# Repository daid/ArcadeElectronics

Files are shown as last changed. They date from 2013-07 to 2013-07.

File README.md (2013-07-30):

ArcadeElectronics
=================

V-USB based Electronics board for Arcade controls

Features
========
* V-USB based USB Interface emulating a mouse, keyboard and gamepad with full configuration of button mapping (no drivers required)
* 4 way digital joystick + 7 button connections. 4 way joystick inputs can also be used for analogue joystick.
* 16 LED output pins (max current total 200mA) which can also be used as inputs. And 8 are also mapped wired to 1A higher power outputs with external power supply (optional hardware)
* RFM12 wireless transiever (optional hardware) allows communication with other controllers and building of wireless controllers with 2 boards.
* Full open-source hardware & open-source software - Build with Free-Open-Source tools (KiCAD & AVR-GCC)
* ISP header to program the AVR (reset line can be cut and re-wired to have the board function as an programmer on the same header)
* USB-micro or USB-B connector depending on your taste
* Different small board designs, depending on your requirements:
	* 100x50mm: Fully featured, has option for 16 LED outputs, of which 8 can be configured for high power. Has wireless RFM12 option. 4 direction inputs, 7 button inputs
	* 50x50mm: Only base features with screw connectors. 4 direction inputs, 7 button inputs.
	* 50x25mm: Only base features with pin connectors. 4 direction inputs, 7 button inputs 
	* 25x25mm: Only base features with pin connectors, components on both sides. 4 direction inputs, 7 button inputs 

Organization
============
The following directories are in this project:
* Electronics - Contain the KiCAD design files
* Software/firmware/bootloader - Modified HIDBoot
* Software/firmware/arcade - Main firmware for the Arcade controller
* Software/computer/commandline - Commandline application to change the controller configuration, and control the LEDs
* Software/computer/lib - Library shared between different applications for custom commands to the ArcadeController
* Software/computer/gui_test - SDL based application to verify the Keyboard/Joystick/Mouse inputs

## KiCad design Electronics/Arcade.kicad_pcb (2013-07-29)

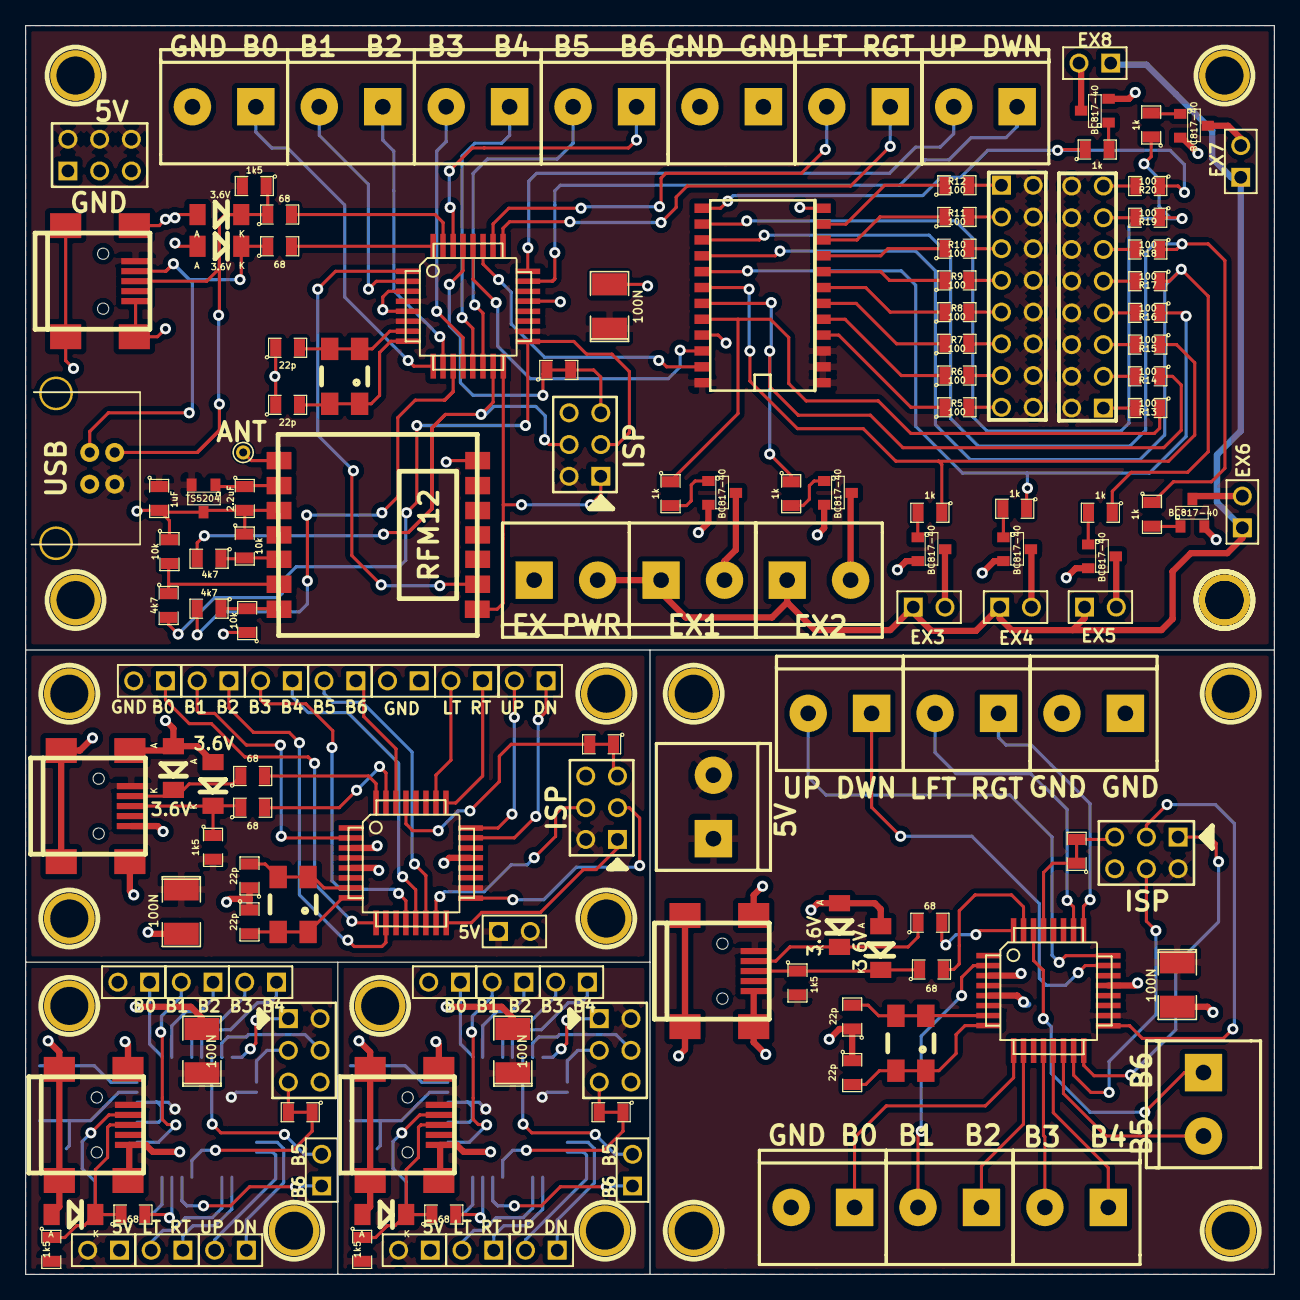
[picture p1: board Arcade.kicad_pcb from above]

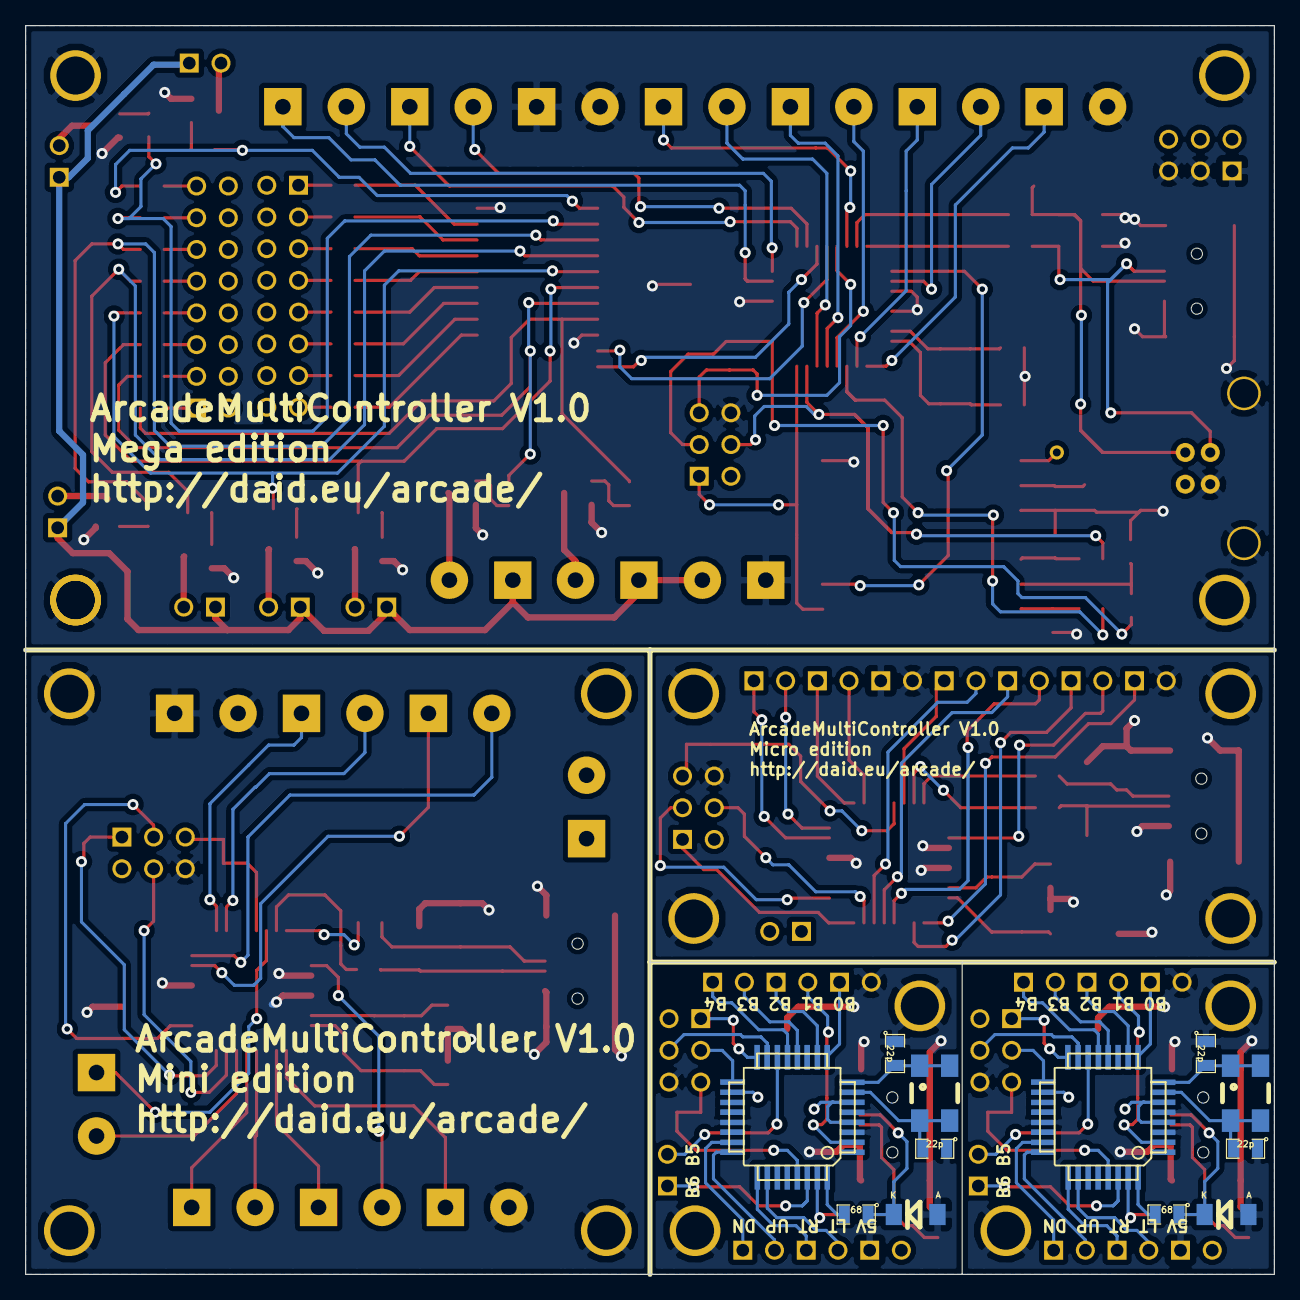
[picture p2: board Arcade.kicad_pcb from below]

Board: 2 copper layers, 100.0 x 100.0 mm, 176 parts (12 on the bottom side), 144 nets.

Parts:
1PIN, 1PIN#2, 1PIN#3, 1PIN#4, 1PIN#5, 1PIN#6, 1PIN#7, 1PIN#8, 1PIN#9, 1PIN#10, 1PIN#11, 1PIN#12, 1PIN#13, 1PIN#14, 1PIN#15, 1PIN#16, 1PIN#17: P***; 1pin
C1, C2, C6, C7, C9, C10, C12, C12#2, C13, C13#2: 22p; SM0805
C3, C8, C11, C14, C14#2: 100N; SM1210L
C4: 1uF; SM0805
C5: 2.2uF; SM0805
CON1, CON2, CON3, CON4, CON4#2: USB-MINI-B; USB_MINI_B
D1, D2, D3, D4, D5, D6, D7, D7#2, D8, D8#2: 3.6V; Diode-MiniMELF_Standard_RevA_27July2010
IC1, IC2, IC3, IC4, IC4#2: ATMEGA8A-A; TQFP32
J1: USB; USB_B_SHORT
P1, P22, P30, P40, P40#2: ISP; pin_array_3x2
P2, P23: UP DWN; mors_2p
P3, P24: LFT RGT; mors_2p
P4, P25: GND GND; mors_2p
P5, P26: B5 B6; mors_2p
P6, P27: B3 B4; mors_2p
P7, P28: B1 B2; mors_2p
P8, P29: GND B0; mors_2p
P9: ANT; PINTST
P10, P11: CONN_8X2; pin_array_8x2
P12: EX1; mors_2p
P13: EX_PWR; mors_2p
P14: CONN_3X2; pin_array_3x2
P15: EX2; mors_2p
P16: EX3; PIN_ARRAY_2X1
P17: EX4; PIN_ARRAY_2X1
P18: EX5; PIN_ARRAY_2X1
P19: EX6; PIN_ARRAY_2X1
P20: EX7; PIN_ARRAY_2X1
P21: EX8; PIN_ARRAY_2X1
P31, P41, P41#2: UP DWN; PIN_ARRAY_2X1
P32, P42, P42#2: LFT RGT; PIN_ARRAY_2X1
P33: GND GND; PIN_ARRAY_2X1
P34, P44, P44#2: B5 B6; PIN_ARRAY_2X1
P35, P45, P45#2: B3 B4; PIN_ARRAY_2X1
P36, P46, P46#2: B1 B2; PIN_ARRAY_2X1
P37, P47, P47#2: GND B0; PIN_ARRAY_2X1
P38, P48, P48#2: 5V; PIN_ARRAY_2X1
P39: 5V; mors_2p
Q1, Q2, Q3, Q4, Q5, Q6, Q7, Q8: BC817-40; SOT23
R1, R35, R39, R43, R43#2: 1k5; SM0805
R2, R3, R36, R37, R40, R41, R44, R44#2, R45, R45#2: 68; SM0805
R4, R38, R42, R46, R46#2: 0; SM0805
R5, R6, R7, R8, R9, R10, R11, R12, R13, R14, R15, R16, R17, R18, R19, R20: 100; SM0805
R21, R22, R23: 4k7; SM0805
R24, R25, R26: 10k; SM0805
R27, R28, R29, R30, R31, R32, R33, R34: 1k; SM0805
U1: PCA9532; SO24E
U2: RFM12
U3: TS5204; SOT23
X1, X2, X3, X4, X4#2: 16Mhz; Crystal_SMD_0603_4Pads_RevA_09Aug2010

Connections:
/B0: IC1.9, P8.1
/B0_2: IC2.9, P29.1
/B0_3: IC3.9, P37.1
/B0_4: IC4.9, IC4#2.9, P47.1, P47#2.1
/B1: IC1.2, P7.2
/B1_2: IC2.2, P28.2
/B1_3: IC3.2, P36.2
/B1_4: IC4.2, IC4#2.2, P46.2, P46#2.2
/B2: IC1.10, P7.1
/B2_2: IC2.10, P28.1
/B2_3: IC3.10, P36.1
/B2_4: IC4.10, IC4#2.10, P46.1, P46#2.1
/B3: IC1.12, P6.2
/B3_2: IC2.12, P27.2
/B3_3: IC3.12, P35.2
/B3_4: IC4.12, IC4#2.12, P45.2, P45#2.2
/B4: IC1.13, P6.1
/B4_2: IC2.13, P27.1
/B4_3: IC3.13, P35.1
/B4_4: IC4.13, IC4#2.13, P45.1, P45#2.1
/B5: IC1.14, P5.2
/B5_2: IC2.14, P26.2
/B5_3: IC3.14, P34.2
/B5_4: IC4.14, IC4#2.14, P44.2, P44#2.2
/B6: IC1.30, P5.1
/B6_2: IC2.30, P26.1
/B6_3: IC3.30, P34.1
/B6_4: IC4.30, IC4#2.30, P44.1, P44#2.1
/BTN_DOWN: IC1.23, P2.1
/BTN_DOWN_2: IC2.23, P23.1
/BTN_DOWN_3: IC3.23, P31.1
/BTN_DOWN_4: IC4.23, IC4#2.23, P41.1, P41#2.1
/BTN_LEFT: IC1.26, P3.2
/BTN_LEFT_2: IC2.26, P24.2
/BTN_LEFT_3: IC3.26, P32.2
/BTN_LEFT_4: IC4.26, IC4#2.26, P42.2, P42#2.2
/BTN_RIGHT: IC1.25, P3.1
/BTN_RIGHT_2: IC2.25, P24.1
/BTN_RIGHT_3: IC3.25, P32.1
/BTN_RIGHT_4: IC4.25, IC4#2.25, P42.1, P42#2.1
/BTN_UP: IC1.24, P2.2
/BTN_UP_2: IC2.24, P23.2
/BTN_UP_3: IC3.24, P31.2
/BTN_UP_4: IC4.24, IC4#2.24, P41.2, P41#2.2
/EX1: P12.2, Q2.3
/EX1_OUT: R13.1, R30.1, U1.20
/EX2: P15.2, Q3.3
/EX2_OUT: R14.1, R29.1, U1.19
/EX3: P16.2, Q4.3
/EX3_OUT: R15.1, R28.1, U1.18
/EX4: P17.2, Q5.3
/EX4_OUT: R16.1, R27.1, U1.17
/EX5: P18.2, Q1.3
/EX5_OUT: R17.1, R31.1, U1.16
/EX6: P19.2, Q6.3
/EX6_OUT: R18.1, R32.1, U1.15
/EX7: P20.2, Q7.3
/EX7_OUT: R19.1, R33.1, U1.14
/EX8: P21.2, Q8.3
/EX8_OUT: R20.1, R34.1, U1.13
/EX_PWR: P12.1, P13.2, P15.1, P16.1, P17.1, P18.1, P19.1, P20.1, P21.1
/MISO: IC1.16, P1.1, U2.1
/MISO_2: IC2.16, P22.1
/MISO_3: IC3.16, P30.1
/MISO_4: IC4.16, IC4#2.16, P40.1, P40#2.1
/MOSI: IC1.15, P1.4, R23.2
/MOSI_2: IC2.15, P22.4
/MOSI_3: IC3.15, P30.4
/MOSI_4: IC4.15, IC4#2.15, P40.4, P40#2.4
/RESET: IC1.29, P1.5, R4.1, R4.2
/RESET_2: IC2.29, P22.5, R38.1, R38.2
/RESET_3: IC3.29, P30.5, R42.1, R42.2
/RESET_4: IC4.29, IC4#2.29, P40.5, P40#2.5, R46.1, R46.2, R46#2.1, R46#2.2
/RF_IRQ: IC1.1, U2.2
/RF_SEL: IC1.11, R21.2
/SCK: IC1.17, P1.3, R22.2
/SCK_2: IC2.17, P22.3
/SCK_3: IC3.17, P30.3
/SCK_4: IC4.17, IC4#2.17, P40.3, P40#2.3
/SCL: IC1.28, U1.22
/SDA: IC1.27, U1.23
/USB_D+: IC1.32, R2.2
/USB_D+_2: IC2.32, R36.2
/USB_D+_3: IC3.32, R40.2
/USB_D+_4: IC4.32, IC4#2.32, R44.2, R44#2.2
/USB_D-: IC1.31, R3.2
/USB_D-_2: IC2.31, R37.2
/USB_D-_3: IC3.31, R41.2
/USB_D-_4: IC4.31, IC4#2.31, R45.2, R45#2.2
/V3.3: C5.1, U2.9, U3.1
GND: 1PIN.1, 1PIN#2.1, 1PIN#3.1, 1PIN#4.1, 1PIN#5.1, 1PIN#6.1, 1PIN#7.1, 1PIN#8.1, 1PIN#9.1, 1PIN#10.1, 1PIN#11.1, 1PIN#12.1, 1PIN#13.1, 1PIN#14.1, 1PIN#15.1, 1PIN#16.1, 1PIN#17.1, C1.1, C2.1, C3.2, C4.2, C5.2, C6.1, C7.1, C8.2, C9.1, C10.1, C11.2, C12.1, C12#2.1, C13.1, C13#2.1, C14.2, C14#2.2, CON1.5, CON1.6, CON1.7, CON1.8, CON1.9, CON2.5, CON2.6, CON2.7, CON2.8, CON2.9, CON3.5, CON3.6, CON3.7, CON3.8, CON3.9, CON4.5, CON4.6, CON4.7, CON4.8, CON4.9, CON4#2.5, CON4#2.6, CON4#2.7, CON4#2.8, CON4#2.9, D1.1, D2.1, D3.1, D4.1, D5.1, D6.1, D7.1, D7#2.1, D8.1, D8#2.1, IC1.3, IC1.5, IC1.21, IC2.3, IC2.5, IC2.21, IC3.3, IC3.5, IC3.21, IC4.3, IC4.5, IC4.21, IC4#2.3, IC4#2.5, IC4#2.21, J1.4, J1.5, J1.6, P1.6, P4.1, P4.2, P8.2, P13.1, P14.1, P14.3, P14.5, P22.6, P25.1, P25.2, P29.2, P30.6, P33.1, P33.2, P37.2, P40.6, P40#2.6, P47.2, P47#2.2, P48.1, P48#2.1, Q1.2, Q2.2, Q3.2, Q4.2, Q5.2, Q6.2, Q7.2, Q8.2, R24.1, R25.1, R26.1, U1.12, U1.21, U2.7, U2.10, U3.3
unnamed: C9.2, IC3.7, X3.2
unnamed: CON2.2, D3.2, R36.1
unnamed: C10.2, IC3.8, X3.1
unnamed: CON2.3, D4.2, R35.1, R37.1
unnamed: C6.2, IC2.7, X2.2
unnamed: C7.2, IC2.8, X2.1
unnamed: CON4.3, CON4#2.3, D8.2, D8#2.2, R43.1, R43#2.1, R45.1, R45#2.1
unnamed: CON4.2, CON4#2.2, D7.2, D7#2.2, R44.1, R44#2.1
unnamed: CON3.3, D6.2, R39.1, R41.1
unnamed: C12.2, C12#2.2, IC4.7, IC4#2.7, X4.2, X4#2.2
unnamed: C13.2, C13#2.2, IC4.8, IC4#2.8, X4.1, X4#2.1
unnamed: CON3.2, D5.2, R40.1
unnamed: R8.1, U1.7
unnamed: P10.1, R12.2
unnamed: R12.1, U1.11
unnamed: P10.3, R11.2
unnamed: R11.1, U1.10
unnamed: R10.1, U1.9
unnamed: R9.1, U1.8
unnamed: R7.1, U1.6
unnamed: R6.1, U1.5
unnamed: R5.1, U1.4
unnamed: P10.15, R5.2
unnamed: P10.13, R6.2
unnamed: P10.11, R7.2
unnamed: P10.9, R8.2
unnamed: P10.7, R9.2
unnamed: P10.5, R10.2
unnamed: C1.2, IC1.7, X1.2
unnamed: C2.2, IC1.8, X1.1
unnamed: P9.1, U2.8
unnamed: P11.15, R20.2
unnamed: Q4.1, R28.2
unnamed: P11.13, R19.2
unnamed: Q3.1, R29.2
unnamed: Q5.1, R27.2
unnamed: Q2.1, R30.2
unnamed: P11.9, R17.2
unnamed: P11.11, R18.2
unnamed: P11.5, R15.2
unnamed: P11.1, R13.2
unnamed: P11.3, R14.2
unnamed: P11.7, R16.2
unnamed: Q7.1, R33.2
unnamed: Q6.1, R32.2
unnamed: Q8.1, R34.2
unnamed: Q1.1, R31.2
unnamed: CON1.3, D2.2, J1.2, R1.1, R3.1
unnamed: CON1.2, D1.2, J1.3, R2.1
unnamed: R21.1, R26.2, U2.14
unnamed: R22.1, R25.2, U2.13
unnamed: R23.1, R24.2, U2.12
VCC: C3.1, C4.1, C8.1, C11.1, C14.1, C14#2.1, CON1.1, CON2.1, CON3.1, CON4.1, CON4#2.1, IC1.4, IC1.6, IC1.18, IC2.4, IC2.6, IC2.18, IC3.4, IC3.6, IC3.18, IC4.4, IC4.6, IC4.18, IC4#2.4, IC4#2.6, IC4#2.18, J1.1, P1.2, P10.2, P10.4, P10.6, P10.8, P10.10, P10.12, P10.14, P10.16, P11.2, P11.4, P11.6, P11.8, P11.10, P11.12, P11.14, P11.16, P14.2, P14.4, P14.6, P22.2, P30.2, P38.1, P38.2, P39.1, P39.2, P40.2, P40#2.2, P48.2, P48#2.2, R1.2, R35.2, R39.2, R43.2, R43#2.2, U1.1, U1.2, U1.3, U1.24, U3.2

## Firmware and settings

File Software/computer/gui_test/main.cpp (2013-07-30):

#include <SDL/SDL.h>
#include "gui.h"

typedef struct
{
    int x, y, w, h;
} keyPos_t;

keyPos_t keyPos[SDLK_LAST];

void init_keyPos();

void draw_button(int active, const char* name, int x, int y, int w, int h)
{
    char buffer[32];
    strcpy(buffer, name);
    buffer[2*w] = '\0';
    buffer[0] = toupper(buffer[0]);
    if (active)
    {
        draw_fill(x * 12, y * 12, w * 12, h * 12);
        draw_text(x * 12 + w * 12 / 2 - strlen(buffer) * 6 / 2, y * 12 + h * 6 - 3, buffer, 0);
    }else{
        draw_rect(x * 12, y * 12, w * 12, h * 12);
        draw_text(x * 12 + w * 12 / 2 - strlen(buffer) * 6 / 2, y * 12 + h * 6 - 3, buffer);
    }
}

int main(int argc, char** argv)
{
    init_gui();
    init_keyPos();
    
    while(true)
    {
        SDL_Event event;
        while (SDL_PollEvent(&event)) 
        {
            switch (event.type) 
            {
            case SDL_QUIT:
                return 0;
            }
        }
        SDL_JoystickUpdate();
        
        int keyCount;
        Uint8* keys = SDL_GetKeyState(&keyCount);
        for(int n=0; n<keyCount; n++)
        {
            if (keyPos[n].x != 0)
            {
                char buffer[64];
                strcpy(buffer, SDL_GetKeyName(SDLKey(n)));
                if (strncmp(buffer, "left ", 5) == 0)
                    strcpy(buffer, buffer + 5);
                if (strncmp(buffer, "right ", 6) == 0)
                    strcpy(buffer, buffer + 6);
                draw_button(keys[n], buffer, keyPos[n].x, keyPos[n].y, keyPos[n].w, keyPos[n].h);
            }else{
                if (keys[n])
                    draw_text(0, 0, SDL_GetKeyName(SDLKey(n)));
            }
        }
        int x, y;
        int button = SDL_GetMouseState(&x, &y);
        draw_button(button & SDL_BUTTON(1), "Left", 1, 18, 2, 2);
        draw_button(button & SDL_BUTTON(2), "Mid", 3, 18, 2, 2);
        draw_button(button & SDL_BUTTON(3), "Right", 5, 18, 2, 2);
        draw_rect(12, 20*12, 6*12, 6*12);
        draw_rect(12 + x * 6*12 / 640, 20*12 + y * 6*12 / 480, 2, 2);
        SDL_GetRelativeMouseState(&x, &y);
        draw_rect(12 + 6*12/2 + x/2, 20*12 + 6*12 / 2 + y/2, 2, 2);
        
        for(int n=0; n<SDL_NumJoysticks(); n++)
        {
            
        }
        
        gui_update();
    }
}


void init_keyPos()
{
    keyPos[SDLK_ESCAPE] = {1, 1, 3, 2};
    
    keyPos[SDLK_F1] = {5, 1, 2, 2};
    keyPos[SDLK_F2] = {7, 1, 2, 2};
    keyPos[SDLK_F3] = {9, 1, 2, 2};
    keyPos[SDLK_F4] = {11, 1, 2, 2};
    keyPos[SDLK_F5] = {14, 1, 2, 2};
    keyPos[SDLK_F6] = {16, 1, 2, 2};
    keyPos[SDLK_F7] = {18, 1, 2, 2};
    keyPos[SDLK_F8] = {20, 1, 2, 2};
    keyPos[SDLK_F9] = {23, 1, 2, 2};
    keyPos[SDLK_F10] = {25, 1, 2, 2};
    keyPos[SDLK_F11] = {27, 1, 2, 2};
    keyPos[SDLK_F12] = {29, 1, 2, 2};

    keyPos[SDLK_BACKQUOTE] = {1, 4, 2, 2};
    keyPos[SDLK_1] = {3, 4, 2, 2};
    keyPos[SDLK_2] = {5, 4, 2, 2};
    keyPos[SDLK_3] = {7, 4, 2, 2};
    keyPos[SDLK_4] = {9, 4, 2, 2};
    keyPos[SDLK_5] = {11, 4, 2, 2};
    keyPos[SDLK_6] = {13, 4, 2, 2};
    keyPos[SDLK_7] = {15, 4, 2, 2};
    keyPos[SDLK_8] = {17, 4, 2, 2};
    keyPos[SDLK_9] = {19, 4, 2, 2};
    keyPos[SDLK_0] = {21, 4, 2, 2};
    keyPos[SDLK_MINUS] = {23, 4, 2, 2};
    keyPos[SDLK_EQUALS] = {25, 4, 2, 2};
    keyPos[SDLK_BACKSPACE] = {27, 4, 4, 2};

    keyPos[SDLK_TAB] = {1, 6, 3, 2};
    keyPos[SDLK_q] = {4, 6, 2, 2};
    keyPos[SDLK_w] = {6, 6, 2, 2};
    keyPos[SDLK_e] = {8, 6, 2, 2};
    keyPos[SDLK_r] = {10, 6, 2, 2};
    keyPos[SDLK_t] = {12, 6, 2, 2};
    keyPos[SDLK_y] = {14, 6, 2, 2};
    keyPos[SDLK_u] = {16, 6, 2, 2};
    keyPos[SDLK_i] = {18, 6, 2, 2};
    keyPos[SDLK_o] = {20, 6, 2, 2};
    keyPos[SDLK_p] = {22, 6, 2, 2};
    keyPos[SDLK_LEFTBRACKET] = {24, 6, 2, 2};
    keyPos[SDLK_RIGHTBRACKET] = {26, 6, 2, 2};
    keyPos[SDLK_BACKSLASH] = {28, 6, 3, 2};

    keyPos[SDLK_CAPSLOCK] = {1, 8, 4, 2};
    keyPos[SDLK_a] = {5, 8, 2, 2};
    keyPos[SDLK_s] = {7, 8, 2, 2};
    keyPos[SDLK_d] = {9, 8, 2, 2};
    keyPos[SDLK_f] = {11, 8, 2, 2};
    keyPos[SDLK_g] = {13, 8, 2, 2};
    keyPos[SDLK_h] = {15, 8, 2, 2};
    keyPos[SDLK_j] = {17, 8, 2, 2};
    keyPos[SDLK_k] = {19, 8, 2, 2};
    keyPos[SDLK_l] = {21, 8, 2, 2};
    keyPos[SDLK_SEMICOLON] = {23, 8, 2, 2};
    keyPos[SDLK_QUOTE] = {25, 8, 2, 2};
    keyPos[SDLK_RETURN] = {27, 8, 4, 2};

    keyPos[SDLK_LSHIFT] = {1, 10, 5, 2};
    keyPos[SDLK_z] = {6, 10, 2, 2};
    keyPos[SDLK_x] = {8, 10, 2, 2};
    keyPos[SDLK_c] = {10, 10, 2, 2};
    keyPos[SDLK_v] = {12, 10, 2, 2};
    keyPos[SDLK_b] = {14, 10, 2, 2};
    keyPos[SDLK_n] = {16, 10, 2, 2};
    keyPos[SDLK_m] = {18, 10, 2, 2};
    keyPos[SDLK_COMMA] = {20, 10, 2, 2};
    keyPos[SDLK_PERIOD] = {22, 10, 2, 2};
    keyPos[SDLK_SLASH] = {24, 10, 2, 2};
    keyPos[SDLK_RSHIFT] = {26, 10, 5, 2};

    keyPos[SDLK_LCTRL] = {1, 12, 3, 2};
    keyPos[SDLK_LSUPER] = {4, 12, 3, 2};
    keyPos[SDLK_LALT] = {7, 12, 3, 2};
    keyPos[SDLK_SPACE] = {10, 12, 9, 2};
    keyPos[SDLK_RALT] = {19, 12, 3, 2};
    keyPos[SDLK_RSUPER] = {22, 12, 3, 2};
    keyPos[SDLK_MENU] = {25, 12, 3, 2};
    keyPos[SDLK_RCTRL] = {28, 12, 3, 2};

    keyPos[SDLK_PRINT] = {32, 1, 2, 2};
    keyPos[SDLK_SCROLLOCK] = {34, 1, 2, 2};
    keyPos[SDLK_PAUSE] = {36, 1, 2, 2};

    keyPos[SDLK_INSERT] = {32, 4, 2, 2};
    keyPos[SDLK_HOME] = {34, 4, 2, 2};
    keyPos[SDLK_PAGEUP] = {36, 4, 2, 2};
    
    keyPos[SDLK_DELETE] = {32, 6, 2, 2};
    keyPos[SDLK_END] = {34, 6, 2, 2};
    keyPos[SDLK_PAGEDOWN] = {36, 6, 2, 2};
    
    keyPos[SDLK_UP] = {34, 10, 2, 2};
    
    keyPos[SDLK_LEFT] = {32, 12, 2, 2};
    keyPos[SDLK_DOWN] = {34, 12, 2, 2};
    keyPos[SDLK_RIGHT] = {36, 12, 2, 2};
    
    keyPos[SDLK_NUMLOCK] = {39, 4, 2, 2};
    keyPos[SDLK_KP_DIVIDE] = {41, 4, 2, 2};
    keyPos[SDLK_KP_MULTIPLY] = {43, 4, 2, 2};
    keyPos[SDLK_KP_MINUS] = {45, 4, 2, 2};

    keyPos[SDLK_KP7] = {39, 6, 2, 2};
    keyPos[SDLK_KP8] = {41, 6, 2, 2};
    keyPos[SDLK_KP9] = {43, 6, 2, 2};
    keyPos[SDLK_KP_PLUS] = {45, 6, 2, 4};

    keyPos[SDLK_KP4] = {39, 8, 2, 2};
    keyPos[SDLK_KP5] = {41, 8, 2, 2};
    keyPos[SDLK_KP6] = {43, 8, 2, 2};

    keyPos[SDLK_KP1] = {39, 10, 2, 2};
    keyPos[SDLK_KP2] = {41, 10, 2, 2};
    keyPos[SDLK_KP3] = {43, 10, 2, 2};
    keyPos[SDLK_KP_ENTER] = {45, 10, 2, 4};

    keyPos[SDLK_KP0] = {39, 12, 4, 2};
    keyPos[SDLK_KP_PERIOD] = {43, 12, 2, 2};
}
